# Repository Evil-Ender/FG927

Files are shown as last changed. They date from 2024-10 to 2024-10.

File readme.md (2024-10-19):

# FG927
## FG927 ver.ESP32H2
    首先，我要先声明一点，我和铃羽同一天生日，所以这个项目叫做FG927，因为它使用了esp32h2，所以是ver.ESP32H2
这是一个基于墨水瓶的GPS码表项目

功能如下：

- 基于GPS的速度显示（一位小数）
- 基于磁力计并使用GPS修正的骑行方向
- 基于陀螺仪的爬坡角度（不怎么工作，过一个减速带就飞了）
- 单程均速、单程极速、单程里程、单程骑行时间、总里程
- 过去十二个小时内的均速、极速统计（精确到分钟）
- 夜间显示照明（最亮可以当手电）
- GPS修正的utc+8时间
- 单程卡路里计算（假设你70kg）
- 气温、气压、高度
- 停止骑行4分钟后自动待机，监测车辆运动自动唤醒
- 续航约九小时（开灯将更短）、低电量待机（从他不能开机到完全没电大概一周）
- 128Mb flash，BLE组成的骑行路线记录功能（待开发）
- **显示铃羽的图片**

## 使用到的关键硬件

- MCU：ESP32-H2-MINI-1
- 陀螺仪：ICM20948
- 电源管理：AXP2101（DCDC1的默认电压必须是3.3V！！！）
- 气压计：MS5611
- LED管理：LP5009
- 墨水屏：GDEY0154D67
- GPS：ATGM336H-5N31
- 功率计：INA219
- flash：W25Q128JVPIQ（未使用）
- 兼容st7789的lcd屏幕，但没有配套的外壳3d建模文件
- 603035 600mah锂电池
- 陶瓷天线：BWGPSCNX18-18B1

## 使用到的库                                       
- Encoder                                                 
- LP50XX                                             
- ArduinoINA219                                         
- XPowersLib                                               https://github.com/lewisxhe/XPowersLib
- SparkFun 9DoF IMU Breakout - ICM 20948 - Arduino Library https://github.com/sparkfun/SparkFun_ICM-20948_ArduinoLibrary/tree/main
- TinyGPSPlus-ESP32                                       
- Adafruit GFX Library                                     
- Adafruit BusIO                                         
- GxEPD2_4G                                                https://github.com/ZinggJM/GxEPD2_4G

## 3D打印外壳
外壳的盖是双色打印的，不双色问题也不大反正，层高是0.08mm，没试过其他的能不能成功，总之精细一点没坏处，他也不需要承受什么巨大的应变。

支架有两种，一种是伸出去的，需要组装，一种是放在把上的，可以根据喜好打印，最好用abs之类的玻璃化转变温度高一点的，pla可能晒一晒就弯了。

需要额外准备M5的螺丝和螺母，以及M3高3mm外径4mm的滚花螺母和M3高5mm头直径6mm厚0.8mm的平头螺丝，M3*8的内六角螺丝。

## pcb

https://oshwhub.com/donchaka0/gps_suzuha

注意，电阻R38用于控制AXP2101的充电模式为LDO模式，以空出DCDC5为GPS供电；电阻R41是编码器PUSH的上拉电阻，已通过ESP32的内部上拉代替，焊接会导致待机时引脚随ALDO3关闭而拉低，这是个BUG。**上述两个电阻不焊接！！！！！**

## 调试

需要使用3.0以上版本的ESP32开发板库才能编译ESP32H2的文件，请一定注意。

测试焊接是否成功时，可以去掉注释BIANCHI.h中#define D_BUG的注释，即可从串口中返回报错数据（除了通讯失败以外的报错信息都很混乱）。

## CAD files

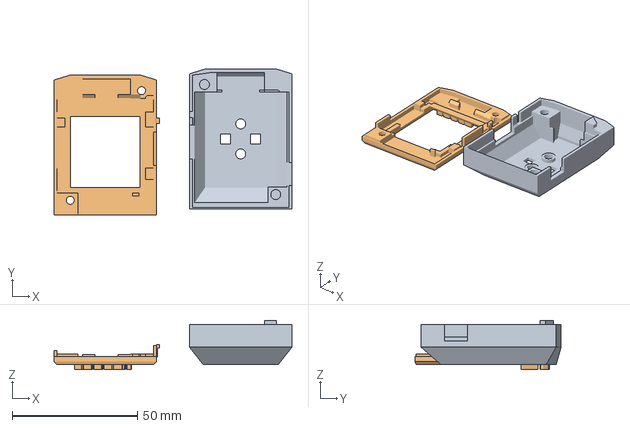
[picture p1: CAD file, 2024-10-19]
3d_model/shell.3mf
95.1 x 58.5 x 19.7 mm
b_tall.STL
组合体

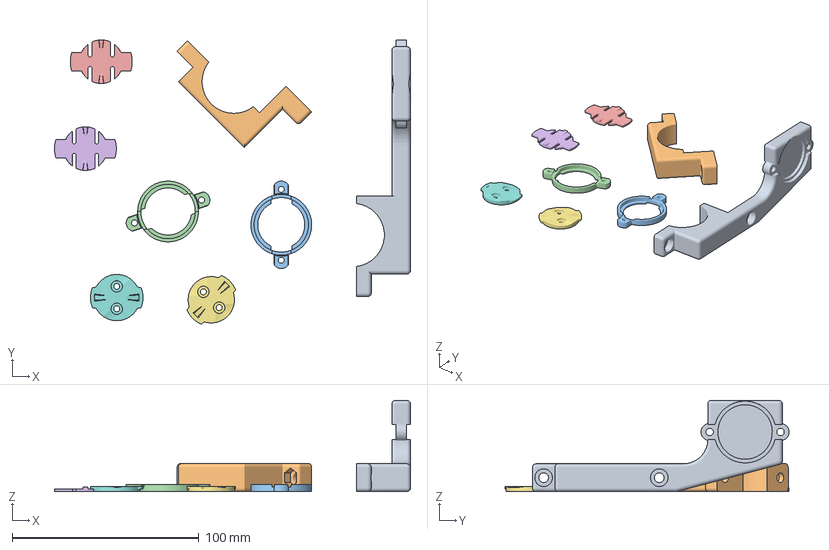
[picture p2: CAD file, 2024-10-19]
3d_model/shelf_simple.3mf
190.9 x 152.4 x 49.0 mm
shelf.STL
bot.STL
hat.STL x 2
Garmin quarter turn socket 2.STL x 2
Garmin quarter turn bayonet.STL x 2

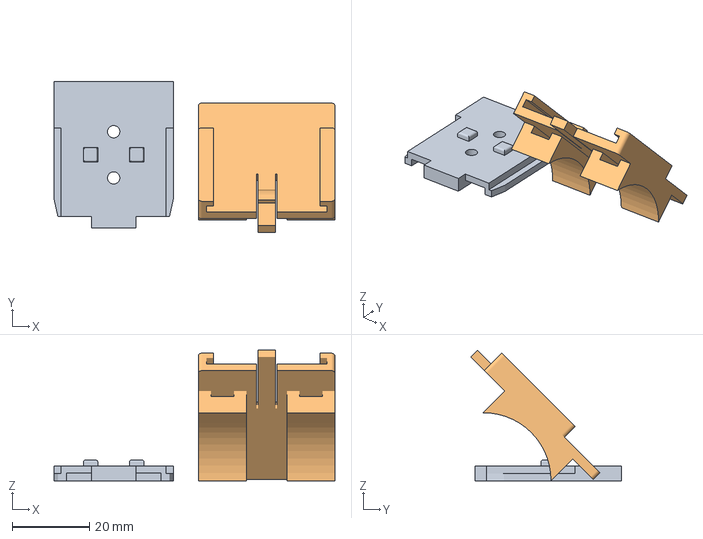
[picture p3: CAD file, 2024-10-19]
3d_model/shelf_more_simple.3mf
73.0 x 39.1 x 33.9 mm
conA.STL
base.STL

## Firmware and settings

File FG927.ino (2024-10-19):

#include "math.h"
#include "soc/rtc.h"
#include "esp_sleep.h"
#include "esp_system.h"
#include "./src/BIANCHI.h"
#define GPIO_WAKEUP_PIN_BITMASK (1ULL << 9)
#define us_s 1000000
TaskHandle_t taskHandleUART = NULL, taskHandleI2C = NULL, taskHandleMenu = NULL;
BIANCHI bianchi;
volatile int mode_menu = 0;
volatile bool flag_enter_menu = false, flag_exit_menu = false;
volatile bool need_batt = true, need_reset = false, need_rTsP = false;
volatile bool flag_go_sleep = false, flag_gps_nothing = true;
volatile bool mode_sunshine = false, need_dis = false, flag_info = false;
bool task_made = false;
bool gps_update = false, sub_update_done = true;
void to_menu();
void TaskUART(void *pvParameters);
void Taski2c(void *pvParameters);
long int push_time = 0;
long int wake_up_time = 1000000 * 10, sleep_level = 1000 * 3, time_menu_dejitters = 100; // in millie
long int t_loop = 0, t_sub_loop = 0, t_end = 0, t_menu_last_push = -100;
uint8_t loop_count = 0, loop_count_sunshine = 0, sunshine_int = 4;
volatile IO_REG_TYPE *pin1_register;
volatile IO_REG_TYPE *pin2_register;
volatile IO_REG_TYPE *pinpush_register;
IO_REG_TYPE pin1_bitmask;
IO_REG_TYPE pin2_bitmask;
IO_REG_TYPE pinpush_bitmask;

uint8_t state;
struct tm time_no_gps;
static ICACHE_RAM_ATTR void isr5(void) { update(); }
static ICACHE_RAM_ATTR void isr22(void) { update(); }
void setup()
{

    // pinMode(22,OUTPUT);
    // digitalWrite(22,1);
    esp_sleep_wakeup_cause_t wakeup_reason = esp_sleep_get_wakeup_cause();
    // Serial.begin(115200);
    if ((wakeup_reason != ESP_SLEEP_WAKEUP_TIMER) && (wakeup_reason != ESP_SLEEP_WAKEUP_EXT1))
    {
        struct tm gpsTime;
        gpsTime.tm_year = 2024;
        gpsTime.tm_mon = 7;   // Month, where 0 = jan
        gpsTime.tm_mday = 1;  // Day of the month
        gpsTime.tm_hour = 12; // Hours since midnight - [0,23]
        gpsTime.tm_min = 0;   // Minutes after the hour - [0,59]
        gpsTime.tm_sec = 0;   // Seconds after the minute - [0,59]
        time_t t = mktime(&gpsTime);
        struct timeval now = {.tv_sec = t};
        settimeofday(&now, NULL);
        bianchi.read_poweron_time();
    }
    // esp_sleep_enable_timer_wakeup(10 * us_s);

    pin1_register = PIN_TO_BASEREG(22);
    pin1_bitmask = PIN_TO_BITMASK(22);
    pin2_register = PIN_TO_BASEREG(5);
    pin2_bitmask = PIN_TO_BITMASK(5);
    pinpush_register = PIN_TO_BASEREG(9);
    pinpush_bitmask = PIN_TO_BITMASK(9);
    delay(10);
    uint8_t s = 0;
    if (DIRECT_PIN_READ(pin1_register, pin1_bitmask))
        s |= 1;
    if (DIRECT_PIN_READ(pin2_register, pin2_bitmask))
        s |= 2;
    state = s;
    while (!bianchi.inst())
    {
    }
    if (bianchi.flag_lowpower_sleep)
    {
        // Serial.printf("flag:%d\n", bianchi.flag_i2c_reading);
        return;
    }
    func_pisition();
    pinMode(5, INPUT_PULLUP);
    pinMode(22, INPUT_PULLUP);
    pinMode(9, INPUT_PULLUP);
    attachInterrupt(5, isr5, CHANGE);
    attachInterrupt(22, isr22, CHANGE);
    // attachInterrupt(9, to_menu, CHANGE);
    // setCpuFrequencyMhz(48);
    // delay(200);
    bianchi.read_GPS();
    xTaskCreate(
        Taski2c, "Task I2C",
        2048,
        NULL,
        2,
        &taskHandleI2C);
    xTaskCreate(
        TaskUART, "Task UART",
        4096,
        NULL,
        1,
        &taskHandleUART);
    xTaskCreate(
        Taskmenu, "Task Menu",
        4096,
        NULL,
        2,
        &taskHandleMenu);
    task_made = true;
    // delay(500);
}

void loop()
{
    bool had_dis = need_dis;
    // struct tm timeinfo;
    // getLocalTime(&timeinfo);
    // Serial.printf("%02d:%02d:%02d", timeinfo.tm_hour, timeinfo.tm_min, timeinfo.tm_sec);
    // Serial.printf("\t%04d %02d %02d\n", timeinfo.tm_year, timeinfo.tm_mon, timeinfo.tm_mday);
    // Serial.printf("flag:%d\n", bianchi.flag_i2c_reading);
    if (flag_go_sleep || bianchi.flag_stop_sleep || bianchi.flag_nogps_sleep || (!bianchi._chag && bianchi.flag_lowpower_sleep))
    {
        // Serial.print("in loop ");
        // Serial.printf("flag:%d\n", bianchi.flag_i2c_reading);
        shut_all();
        // Serial.print(" after shut");

        if (bianchi.flag_stop_sleep)
        {
            esp_sleep_enable_ext1_wakeup((1ULL << 14) | (1ULL << 9), ESP_EXT1_WAKEUP_ANY_LOW);
        }
        else
        {
            esp_sleep_enable_ext1_wakeup(1ULL << 9, ESP_EXT1_WAKEUP_ANY_LOW);
        }
        if (bianchi.flag_lowpower_sleep)
        {
            bianchi.display_map(suzuha_lowpower);
        }
        else
        {
            bianchi.display_map(suzuha2);
        }
        bianchi.shut_power();
        esp_deep_sleep_start();
    }

    while (!bianchi.flag_gps_update)
    {
        // int a = 2;
        delay(10);
    }
    bianchi.flag_gps_update = false;
    need_rTsP = true;
    long int sub_time = millis();
    bianchi.display_dis(need_dis);
    bool invert;
    invert = !mode_sunshine || loop_count_sunshine;
    loop_count_sunshine = loop_count_sunshine > sunshine_int ? 0 : loop_count_sunshine + 1;
    bianchi.display_all(invert, mode_menu);

    for (int sub_dis = 0; sub_dis < 1; sub_dis++)
    {
        while ((millis() - sub_time) < 500)
        {
        }
        sub_time = millis();
        bianchi.display_dis(need_dis);
        bianchi.display_all(1, mode_menu);
    }
    need_batt = true;
    if (had_dis)
    {
        need_dis = false;
    }
    // delay(2);
}

void Taskmenu(void *pvParameters)
{
    bool last_state = true;
    while (1)
    {
        bool state = digitalRead(9);
        if (last_state != state)
        {
            delay(50);
            if (state == false) // push
            {
                push_time = millis();

                if (mode_menu == 2) // menu info reset
                {
                    if (bianchi.position_menu > 15)
                    {
                        bianchi.first_IMU_read = 0;
                    }
                    if (bianchi.position_menu > 5 && bianchi.position_menu <= 15)
                    {
                        bianchi.info = true;
                    }
                    if (bianchi.position_menu <= -5)
                    {
                        bianchi.reset_single_ride();
                    }
                    bianchi.position_menu = 0;
                }
            }
            else // relese
            {
                if (mode_menu == 0 && bianchi.info)
                {
                    bianchi.info = false;
                    bianchi.position_info = 0;
                }
                else
                {
                    mode_menu = mode_menu == 2 ? 0 : mode_menu + 1; // final
                }

                flag_go_sleep = (millis() - push_time) > sleep_level ? true : false;
            }
            last_state = state;
        }
        delay(5);
    }
}

void Taski2c(void *pvParameters)
{
    while (1)
    {
        if (flag_go_sleep || bianchi.flag_stop_sleep || bianchi.flag_nogps_sleep || bianchi.flag_i2c_reading)
        {
            delay(20);
            continue;
        }
        bianchi.flag_i2c_reading = true;
        bianchi.read_IMU();
        if (need_rTsP)
        {
            //useless chip
            need_rTsP = false;
        }
        if (need_batt)
        {
            bianchi.read_T_start_P();
            delay(20);
            bianchi.read_batt();
            bianchi.readCurrent();
            bianchi.read_P_start_T();
            need_batt = false;
        }
        if (mode_menu && bianchi.position_old != bianchi.position)
        {
            func_pisition();
        }
        if (!mode_menu)
        {
            if (bianchi.speed < 1 && bianchi.position_old > 1 && !bianchi.info)
            {
                for (int ii = bianchi.position_old; ii > 1; ii--)
                {
                    bianchi.setlumi(ii);
                    delay(5);
                }
                bianchi.setlumi(0, 0);
                bianchi.setlumi(0, 2);
                bianchi.setlumi(0, 3);
                bianchi.setlumi(0, 5);
                bianchi.setlumi(0, 6);
                bianchi.setlumi(0, 8);
                bianchi.position_old = 1;
            }
            if (bianchi.speed >= 1 && bianchi.position_old == 1 && bianchi.position > 1)
            {
                for (int ii = 1; ii < bianchi.position; ii++)
                {
                    bianchi.setlumi(ii);
                    delay(5);
                }
                bianchi.position_old = bianchi.position;
            }
        }
        bianchi.flag_i2c_reading = false;
        delay(5);
    }
}

inline void func_pisition()
{
    if (bianchi.position_old == 1 && bianchi.position > 1)
    {
        for (int ii = 1; ii < bianchi.position; ii++)
        {
            bianchi.setlumi(ii);
            delay(8);
        }
        bianchi.position_old = bianchi.position;
        return;
    }
    if (bianchi.position < 256 && bianchi.position >= 0)
    {
        bianchi.setlumi(bianchi.position);
        need_reset = false;
        flag_info = false;
    }
    if (bianchi.position < 0 && bianchi.position >= -10)
    {
        bianchi.setlumi(0);
        // if (mode_sunshine)
        // {
        //     need_dis = true;
        // }
        mode_sunshine = false;
        need_reset = false;
        flag_info = false;
    }
    if (bianchi.position < -10 && bianchi.position >= -15)
    {
        mode_sunshine = true;
        need_reset = false;
        sunshine_int = 3;
        flag_info = false;
    }

    if (bianchi.position < -15 && bianchi.position >= -20)
    {
        mode_sunshine = true;
        need_reset = false;
        sunshine_int = 0;
        flag_info = false;
    }
    // if (bianchi.position < -20 && bianchi.position >= -25) // info
    // {
    //     mode_sunshine = false;
    //     flag_info = true;
    //     need_reset = false;
    // }
    // if (bianchi.position < -25 && bianchi.position >= -30)
    // {
    //     mode_sunshine = false;
    //     need_reset = true;
    //     flag_info = false;
    // }
    bianchi.position_old = bianchi.position;
    Serial.println(bianchi.position);
}

void TaskUART(void *pvParameters)
{
    while (1)
    {
        bianchi.read_GPS();
        delay(20);
        // Serial.println("sub print");
    }
}

void update()
{
    if (!mode_menu && !bianchi.info)
    {
        return;
    }
    uint8_t p1val = DIRECT_PIN_READ(pin1_register, pin1_bitmask);
    uint8_t p2val = DIRECT_PIN_READ(pin2_register, pin2_bitmask);
    uint8_t ustate = state & 3;
    if (p1val)
        ustate |= 4;
    if (p2val)
        ustate |= 8;
    state = (ustate >> 2);
    if (mode_menu == 1)
    {
        switch (ustate)
        {
        case 1:
        case 7:
        case 8:
        case 14:
            bianchi.position += 1;
            break;
        case 2:
        case 4:
        case 11:
        case 13:
            bianchi.position -= 1;
            break;
        case 3:
        case 12:
            bianchi.position += 2;
            break;
        case 6:
        case 9:
            bianchi.position -= 2;
            break;
        }
        if ((bianchi.position - bianchi.position_old) > 8)
        {
            bianchi.position = bianchi.position_old;
        }
        bianchi.position = bianchi.position > 255 ? 255 : bianchi.position;
        bianchi.position = bianchi.position < -20 ? -20 : bianchi.position;
        return;
    }

    if (mode_menu == 2)
    {
        switch (ustate)
        {
        case 1:
        case 7:
        case 8:
        case 14:
            bianchi.position_menu += 1;
            break;
        case 2:
        case 4:
        case 11:
        case 13:
            bianchi.position_menu -= 1;
            break;
        case 3:
        case 12:
            bianchi.position_menu += 2;
            break;
        case 6:
        case 9:
            bianchi.position_menu -= 2;
            break;
        }
        bianchi.position_menu = bianchi.position_menu > 25 ? 25 : bianchi.position_menu;
        bianchi.position_menu = bianchi.position_menu < -15 ? -15 : bianchi.position_menu;
        return;
    }

    if (bianchi.info)
    {
        switch (ustate)
        {
        case 1:
        case 7:
        case 8:
        case 14:
            bianchi.position_info += 1;
            break;
        case 2:
        case 4:
        case 11:
        case 13:
            bianchi.position_info -= 1;
            break;
        case 3:
        case 12:
            bianchi.position_info += 2;
            break;
        case 6:
        case 9:
            bianchi.position_info -= 2;
            break;
        }
        bianchi.position_info = bianchi.position_info > limit_speed_dis / 10 ? limit_speed_dis / 10 : bianchi.position_info;
        bianchi.position_info = bianchi.position_info < 0 ? 0 : bianchi.position_info;
        return;
    }
}

void shut_all()
{
    detachInterrupt(22);
    detachInterrupt(5);
    detachInterrupt(9);
    // Serial.print(" before i2c wait ");
    // Serial.printf("flag:%d\n", bianchi.flag_i2c_reading);
    while (bianchi.flag_i2c_reading)
    {
        delay(1);
    }
    bianchi.flag_i2c_reading = true;
    if (task_made)
    {
        // Serial.print(" before delete ");
        vTaskDelete(taskHandleI2C);
        vTaskDelete(taskHandleUART);
        vTaskDelete(taskHandleMenu);
        taskHandleI2C = NULL;
        taskHandleUART = NULL;
        taskHandleMenu = NULL;
        task_made = false;
    }
    // Serial.print(" after shut");
    bianchi.setlumi(0);
}

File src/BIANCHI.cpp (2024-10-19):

#include "BIANCHI.h"

// device
XPowersPMU myPMU;
INA219 ina219;
SPIClass hspi(FSPI);
LP50XX lp5009;
TinyGPSPlus gps;
ICM_20948_I2C ICM;
MS5611 ms5611;
RTC_DATA_ATTR struct tm time_begin, time_dis[24];
RTC_DATA_ATTR bool flag_gps_update_firsttime = false, flag_lowpower_rtc = false, flag_speed_dis_clear = false;
RTC_DATA_ATTR double diff_gps_poweron = 0, single_ride_dis = 0, single_ride_average_speed = 0;
RTC_DATA_ATTR int single_ride_time = 0, working_time = 0;
RTC_DATA_ATTR double total_ride_dis = 0;
RTC_DATA_ATTR int rtc_position = -5;
RTC_DATA_ATTR volatile uint8_t speed_dis[limit_speed_dis], speed_dis_max[limit_speed_dis], speed_max = 0;
RTC_DATA_ATTR int pointer_speed_dis_inMinute = 0;
RTC_DATA_ATTR float carlo = 0;
volatile bool isrFi1red = false;
double single_ride_dis_last = 0;
uint8_t BIANCHI::_lumi[9] = {0, 0, 0, 0, 0, 0, 0, 0, 0};
uint8_t speed_max_minute = 0;
U8G2_FOR_ADAFRUIT_GFX u8g2Fonts;
// EPD
#define ENABLE_GxEPD2_GFX 1
#include "map_suzu.h"
#include "map_suzu2.h"
#include "num96_48.h"
#include "num48_24.h"
#include "map.h"
#include "batt.h"
#include "ionic.h"
#include "GxEPD2_4G_BW.h"
#include "GxEPD2_4G_4G.h"
// #include "GxEPD2_4G_display_selection_new_style.h"
#include <Fonts/FreeMonoBold9pt7b.h>
// #include "GxEPD2_display_selection_new_style.h"
GxEPD2_4G_BW<GxEPD2_154_GDEY0154D67, (GxEPD2_154_GDEY0154D67::HEIGHT <= 65536ul / (GxEPD2_154_GDEY0154D67::WIDTH / 8) ? GxEPD2_154_GDEY0154D67::HEIGHT : 65536ul / (GxEPD2_154_GDEY0154D67::WIDTH / 8))> display(GxEPD2_154_GDEY0154D67(1, 2, 3, 4));
GxEPD2_4G_4G<GxEPD2_154_GDEY0154D67, (GxEPD2_154_GDEY0154D67::HEIGHT <= 65536ul / (GxEPD2_154_GDEY0154D67::WIDTH / 8) ? GxEPD2_154_GDEY0154D67::HEIGHT : 65536ul / (GxEPD2_154_GDEY0154D67::WIDTH / 8))> display_4G(GxEPD2_154_GDEY0154D67(1, 2, 3, 4));
BIANCHI::BIANCHI()
{
}

bool BIANCHI::inst()
{
    position = rtc_position;
    position_old = position;
    u8g2Fonts.setFont(u8g2_font_wqy16_t_gb2312);
    u8g2Fonts.setFontMode(1);                  // use u8g2 transparent mode (this is default)
    u8g2Fonts.setFontDirection(0);             // left to right (this is default)
    u8g2Fonts.setForegroundColor(GxEPD_WHITE); // apply Adafruit GFX color
    u8g2Fonts.setBackgroundColor(GxEPD_BLACK); // apply Adafruit GFX color
    hspi.begin(_SCK, _MISO, _MOSI, _EPD_CS);
    Wire.begin(_SDA, _SCL, 400000);
    Serial0.begin(9600, SERIAL_8N1, 23, 24);
    myPMU.begin(Wire, AXP2101_SLAVE_ADDRESS, 8, 10);
    Serial.begin(9600);
    read_batt();
    if (flag_lowpower_rtc && !_chag && _batt <= 5)
    {
        flag_lowpower_sleep = true;
        flag_i2c_reading = false;
        myPMU.setChargingLedMode(XPOWERS_CHG_LED_BLINK_4HZ);
        delay(2000);
        myPMU.setChargingLedMode(XPOWERS_CHG_LED_CTRL_CHG);
        return true;
    }
    myPMU.disableALDO2();
    D_mailln("OHA!");
    display_4G.epd2.selectSPI(hspi, SPISettings(4000000, MSBFIRST, SPI_MODE0));
    display.epd2.selectSPI(hspi, SPISettings(4000000, MSBFIRST, SPI_MODE0));
    display.init(115200, true, 2, false);
    display_4G.init(115200, true, 2, false);
    display_map(0);
    display.setRotation(0);
    display.setFont(&FreeMonoBold9pt7b);
    display.setPartialWindow(0, 0, 200, 200); // 设置部分窗口
    display.setTextColor(my_black);
    u8g2Fonts.begin(display);
    display.firstPage();
    conn_test();
    if (shippai_code[0])
    {
        D_mailln("AXP2101 transmission shippai shita!");
        return false;
    }
    // myPMU.reset();
    delay(50);
    myPMU.setALDO3Voltage(3300);
    myPMU.enableALDO3();
    myPMU.setALDO1Voltage(3300);
    myPMU.enableALDO1();
    myPMU.disableDC2();
    myPMU.disableDC3();
    myPMU.disableDC4();
    myPMU.setALDO2Voltage(1800);
    myPMU.enableALDO2();
    myPMU.setDC5Voltage(3300);
    myPMU.enableDC5();
    myPMU.setALDO4Voltage(3000);
    myPMU.enableALDO4();
    myPMU.setChargeTargetVoltage(XPOWERS_AXP2101_CHG_VOL_4V2);
    myPMU.setChargingLedMode(XPOWERS_CHG_LED_CTRL_CHG);
    myPMU.setPowerKeyPressOffTime(XPOWERS_POWEROFF_4S);
    myPMU.setChargerConstantCurr(XPOWERS_AXP2101_CHG_CUR_300MA);
    delay(200);
    if (shippai_shita())
    {
        return false;
    }

    lp5009.Begin(_ADD_LP5009);
    lp5009.SetScaling(LOG_SCALE_ON);
    setlumi(64, 0);
    setlumi(64, 1);
    setlumi(64, 2);
    delay(100);
    // inst INA
    ina219.begin();
    ina219.configure(INA219::RANGE_16V, INA219::GAIN_2_80MV, INA219::ADC_16SAMP, INA219::ADC_16SAMP, INA219::CONT_SH_BUS);
    ina219.calibrate(R_SHUNT, V_SHUNT_MAX, V_BUS_MAX, I_MAX_EXPECTED);
    lastread = millis();
    ms5611.setI2Caddr(_ADD_MS5611);
    ms5611.set_wire();
    ms5611.ReadProm();
    ms5611.start_mesure(T_OSR);
    delay(100);
    while (!init_IMU())
    {
    }
    setlumi(64, 3);
    setlumi(64, 4);
    setlumi(64, 5);
    while (!init_DMP())
    {
    }
    setlumi(64, 6);
    setlumi(64, 7);
    setlumi(64, 8);
    delay(500);
    blink();
    count_stop = 0;
    for (int ii = 0; ii < limit_stop; ii++)
    {
        speed_stop[ii] = 0;
    }
    if (!flag_speed_dis_clear)
    {
        for (int ii = 0; ii < limit_speed_dis; ii++)
        {
            speed_dis[ii] = 0;
            D_mailln(speed_dis[ii]);
        }
        for (int ii = 0; ii < limit_speed_dis; ii++)
        {
            speed_dis_max[ii] = 0;
            D_mailln(speed_dis_max[ii]);
        }
        tm time_clear;
        time_clear.tm_hour = 0;
        time_clear.tm_min = 0;
        time_clear.tm_sec = 0;
        for (int ii = 0; ii < limit_speed_dis / 60 * 2; ii++)
        {
            time_dis[ii] = time_clear;
        }
        flag_speed_dis_clear = true;
    }
    flag_stop_sleep = false;
    flag_nogps_sleep = false;
    return true;
}
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

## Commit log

2024-10-19 init repo
    [shelf_more_simple.3mf, shelf_simple.3mf, shell.3mf]
2024-10-19 add pcb notice
